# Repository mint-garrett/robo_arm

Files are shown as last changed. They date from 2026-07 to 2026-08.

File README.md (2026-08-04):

This is another robotic arm project.
As of now, the project consists of:

Hardware:
- SBC: Raspberry Pi 4B
- 4 MG90 servos
- Custom power distribution PCB to distribute 5V @ 3A to aforementioned servos

Software:
- All code is written in Python, as it is easy and works well with the Pi4B.
- 2 function defining scripts, 1 configuration file and 1 main executable script

Design:
- 3D printed PLA frame designed in Fusion360 and printed on A1 Mini

More details are provided in the respective README.mds in each folder.

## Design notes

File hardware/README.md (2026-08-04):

I ended up having to design a custom power distribution PCB because the Axiometa PCB did not work.

The Altium project files are in this folder, while the 8 Gerber files + drill file are in the gerber_files folder

The board, in a nutshell, pulls 5V @ 3A from an Apple USB-C charger to distribute to 4 servo motors.
It is defined for that power specification, so I would not recommend using anything besides that specific setup.

All the capacitor pairs exist to 1: serve as power reserves and 2: to filter noise, as servos are very spontaneous in their current draw.
100nF ceramics: a standard for high frequency, local filtering
22uF electrolytic calcs (using C = (I × Δt) / ΔV): .3A (stall current for my servos) * 2us (general time transient for current)/ .2 (5 percent of 5V rail) = 24uF
    **I should have used .2 V as the acceptable voltage sag, which stems from the 4.8V minimum operating voltage from the datasheet (yields 30uF)
220uF bulk: I found 10x the local cap's amount is a some kind of general rule, so I did that.

Most of the routing and other design choices are self explanatory by the schematics and pcb file. The GND via far away from everything else is for the pi4b to reference the servo GND to create accurate PWM signals.

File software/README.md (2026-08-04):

Software README.md:

config.py - contains all data (MOTORS dict and important variables) needed for the coords.py and movment_functions.py. 

coords.py - defines all functions related to the arm's position in space (degree_vector_init(), update_degree_vector())

movement_functions.py - contains the move() function, which basically serves as the project's main function.

working_main.py - starts the pigpiod daemon and the move() function

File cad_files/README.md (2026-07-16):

These are all the CAD files I created for this project.

All screw holes are designed for M3 screws (~3mm diameter).

arm_base = desgined to be large enough to fit a Pi4B and a breadboard with extra room in all directions.

base_cover = screws on to top of arm_base

servo_wrapper = mounts 1st servo to arm_base 

second_joint_v2 = i designed this to fit on to any normal servo horn, i personally hot glued it but there are other options. 
"half moon" portion at the end is designed to distribute weight of arm assembly onto the servo_wrapper. 
large wall portion is meant to act as a spot to mount another servo_wrapper at 45 deg. i drilled holes with 9/64 drill bit because I was too lazy to cad the holes.

3rd_joint_custom_horn = this isn't a great fit, but it works. screw onto servo as you would with any other horn, but you may have to push it down some, mine was too thick.
holes at the end are for another servo_wrapper and servo.

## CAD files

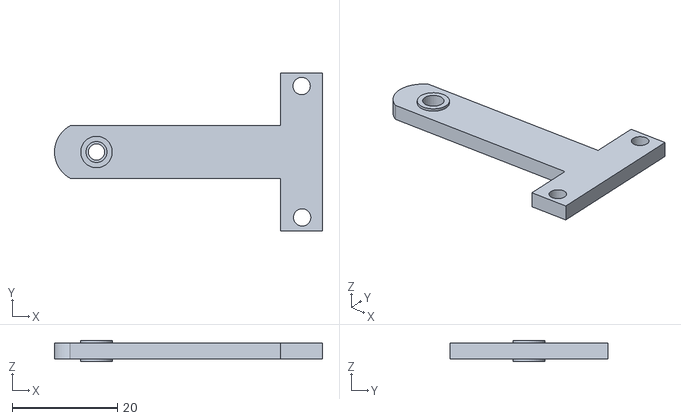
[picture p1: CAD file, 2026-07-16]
cad_files/3rd_joint_custom_horn.stl
51.0 x 30.0 x 4.00

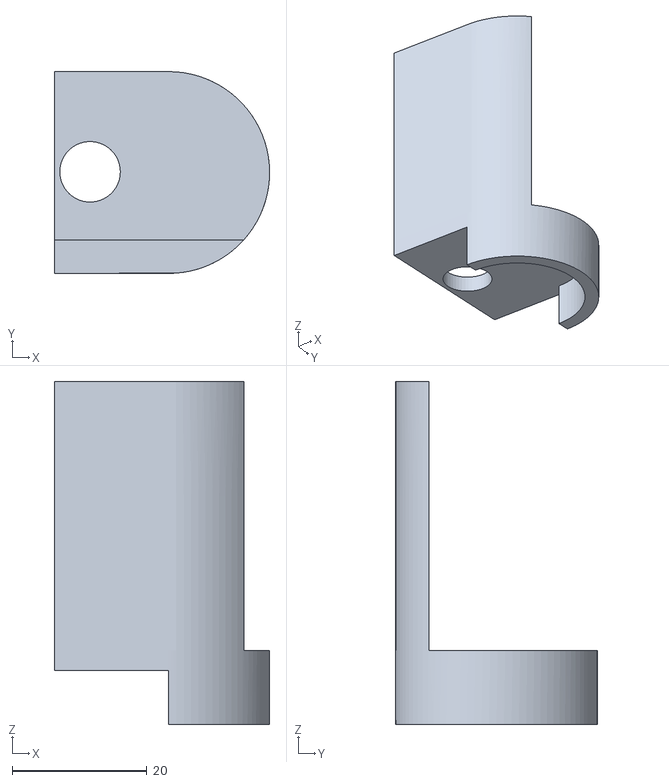
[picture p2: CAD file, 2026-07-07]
cad_files/second_jointv2.stl
32.0 x 30.0 x 51.0

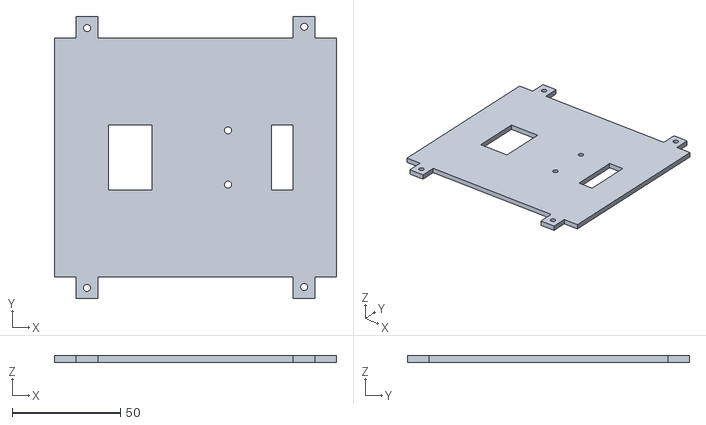
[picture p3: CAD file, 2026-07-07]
cad_files/base_cover.stl
130.0 x 130.0 x 3.00

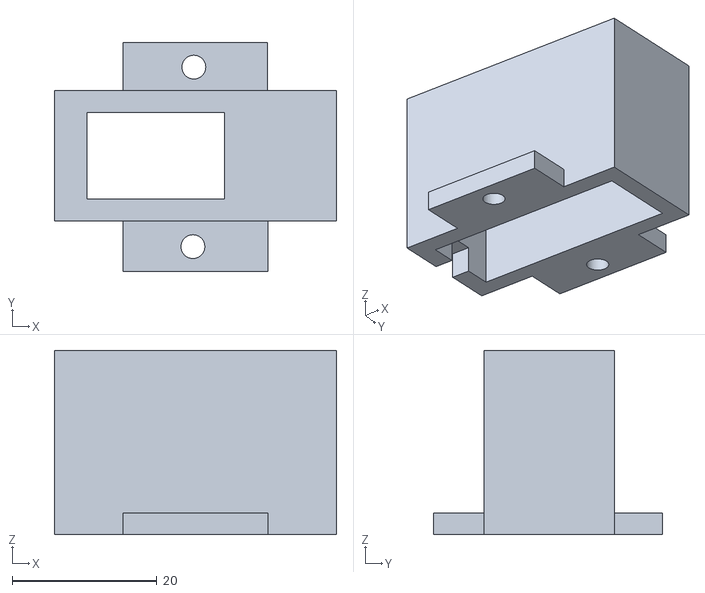
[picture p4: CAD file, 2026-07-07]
cad_files/servo_wrapper.stl
39.0 x 31.7 x 25.5

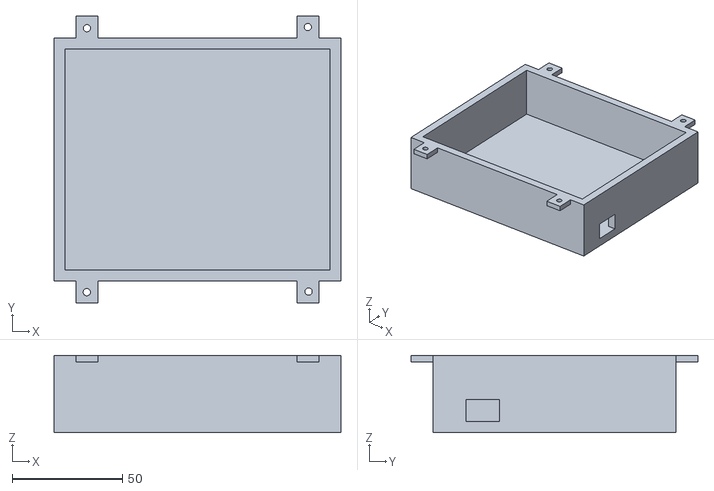
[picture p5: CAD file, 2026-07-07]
cad_files/arm_base.stl
130.0 x 130.0 x 35.0

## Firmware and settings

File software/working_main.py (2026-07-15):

import pigpio
import subprocess
import time

from movement_functions import move, MOTORS

try:
    subprocess.run("sudo pigpiod", timeout = 5, shell = True)
    print("subprocess executed")
    time.sleep (2)
except subprocess.TimeoutExpired as f:
    print(f"pigpiod is started but timed out waiting: {f}")
except subprocess.CalledProcessError as e:
    print(f"sudo pigpiod failed to execute: {e}")


pi = pigpio.pi()
if not pi.connected:
    print("daemon not working")
    raise SystemExit

for m in MOTORS.values():
    pi.set_mode(int(m["pin"]), pigpio.OUTPUT)

try:
    move(pi)
finally:
    for m in MOTORS.values():
        pi.set_servo_pulsewidth(m["pin"],0)
    pi.stop()

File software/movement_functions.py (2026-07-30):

import pigpio
import select
import sys
import termios
import time
import tty

from config import period, POS_0, POS_180, POS_90, MOTORS, step, repeat_key_buffer, delay
from coords import degree_vector_init, update_degree_vector

degree_vector = degree_vector_init()

#returns key input as a string for move fn
def get_key():
    if select.select([sys.stdin], [], [], 0)[0]:
        return sys.stdin.read(1)
    return None

##early move function, used to initialize move function
def move_to(pi, pin, pulse_width):
    pulse_width = max(POS_0, min(POS_180, pulse_width))
    pi.set_servo_pulsewidth(pin, pulse_width)
    return pulse_width

def move(pi):
    #all motors to starting positions
    for m in MOTORS.values():
        move_to(pi,m["pin"], m["wf_pos"])
    time.sleep(.5)

    ##gets current terminal attributes and switces to cbreak for character-by character interpretation
    fd = sys.stdin.fileno()
    old_settings = termios.tcgetattr(fd)
    tty.setcbreak(fd)
    
    try:
        print("starting!")
        while True:
            key = get_key()
            if key is None:
                time.sleep(delay)
                continue
            #master exit
            if key == '\x1b':
                break
                
            current_time= time.time()

            for name, m in MOTORS.items():
                k = m["key_bindings"]
                if key not in (k["to_0"],k["to_90"],k["to_180"]):
                    continue
                key_accept = False
                if key == k["to_90"]:
                    key_accept = True
                elif key != m["last_key"]:
                    key_accept = True
                elif (current_time - m["last_key_time"]) >= repeat_key_buffer:
                    key_accept = True

                if key_accept: #allows movement incrementally, or to the middle position
                    if key == k['to_0']:
                        m["old_wf_pos"] = m["wf_pos"]

                        if m["wf_pos"] <= POS_0:
                            step_applied = 0
                        else:
                            step_applied = step

                        m["wf_pos"] -= step_applied
                        print(f"{m["location"]}    key = {k["to_0"]}   wf len = {m["wf_pos"]}")
                        update_degree_vector(degree_vector, m["idx"], m["wf_pos"], m["old_wf_pos"])  

                    elif key == k['to_180']:
                        m["old_wf_pos"] = m["wf_pos"]

                        if m["wf_pos"] <= POS_0:
                            step_applied = 0
                        else:
                            step_applied = step

                        m["wf_pos"] += step_applied
                        print(f"{m["location"]}    key = {k["to_180"]}   wf len = {m["wf_pos"]}")
                        update_degree_vector(degree_vector, m["idx"], m["wf_pos"], m["old_wf_pos"])

                    elif key == k['to_90']:
                        m["old_wf_pos"] = m["wf_pos"]
                        m["wf_pos"] = POS_90
                        print(f"{m["location"]}    key = {k["to_90"]}  center wf: {m["wf_pos"]}")
                        update_degree_vector(degree_vector, m["idx"], m["wf_pos"], m["old_wf_pos"])
                        
                    
                    m["wf_pos"] = move_to(pi, m["pin"],m["wf_pos"])                 
                    m["last_key"] = key 
                    m["last_key_time"] = current_time
                    print(f"{degree_vector}/n")
                break      
            time.sleep(delay)

    finally:
        #resets terminal to normal
        termios.tcsetattr(fd, termios.TCSADRAIN, old_settings)
        print("exiting!")

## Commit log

2026-05-25 first commit of servo test code
2026-07-03 got servo sort of moving
2026-07-05 servo precision control achieved
2026-07-07 add servo dict. edit move function for dict compatibility.
2026-07-07 uploading cad files
    [arm_base.stl, base_cover.stl, second_jointv2.stl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]
2026-07-07 fixed indentation issues. fixed decoy values in motor dict that were causing set errors. fixed faulty for loop break point as well
    [movement_functions.py, working_main.py]
2026-07-11 i kept forgetting to run sudo pigpiod. i fixed that
    [working_main.py]
2026-07-15 increase robustness of shell subprocess error handling
    [working_main.py]
2026-07-16 Create README.md for CAD files documentation
2026-07-24 adds id to MOTORS dict for more information in UI
2026-07-24 initial commit. stages main functions
2026-07-29 moves motor dict and setup variables to separate config file to avoid circular imports
    [config.py]
2026-07-30 adds deg/us variable for degree vector calculation and idx element to MOTORS dict for appending degree values to degree vector
2026-08-04 Add README for custom power distribution PCB
2026-08-04 adds power board Altium files
    [main_schematic.SchDoc, pi_power_board.PrjPcb, pi_power_pcb.PcbDoc]
2026-08-04 Update README with details on PCB files
2026-08-04 Add placeholder file in gerber_files directory
2026-08-04 adds gerber files
    [pi_power_pcb.gbl, pi_power_pcb.gbo, pi_power_pcb.gbs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]
2026-08-04 Update README with detailed PCB design information
